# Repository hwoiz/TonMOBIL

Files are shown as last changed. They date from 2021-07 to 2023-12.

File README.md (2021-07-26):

# TonMOBIL-Box
## Meine Box
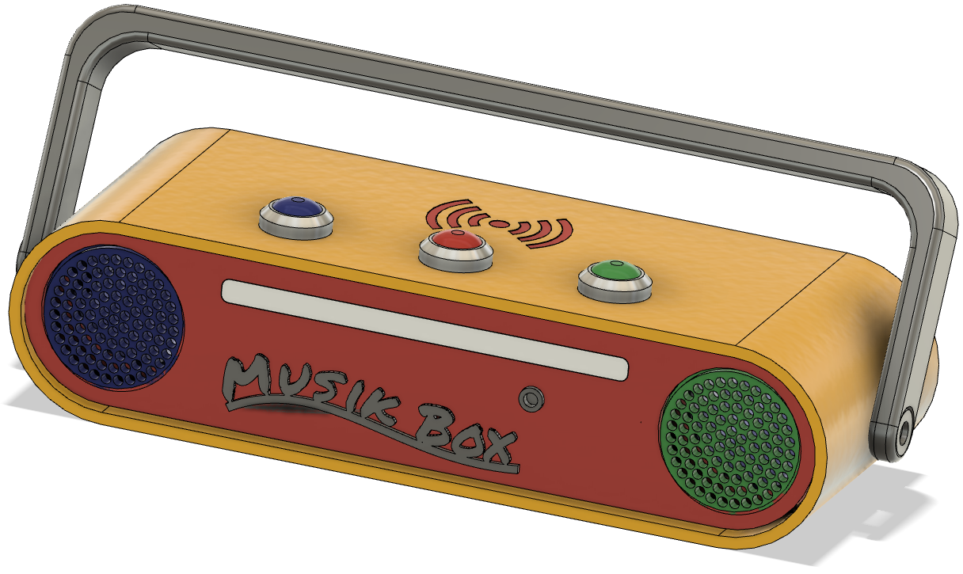
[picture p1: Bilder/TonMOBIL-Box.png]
TonMOBIL-Box

## Danksagung
Als Vorlage für mein Projekt diente das Projekt TonUINO von Thorsten Voß.
[https://www.voss.earth/tonuino](https://www.voss.earth/tonuino)

Viele Forenbeiträge aus [https://discourse.voss.earth](https://discourse.voss.earth/) haben mich animiert eine eigene Variante zu erstellen.
## Einleitung
Die Zeiten von Kasseten und CD sind inzwischen vorbei. Heute sind MP3-Dateien das Medium der Wahl.
Die TonMOBIL-Box basiert auf dem OpenSource Projekt TonUNIO. Es ermöglicht auch Kleinkindern selbstständig ihre Lieblings-MP3 abzuspielen. Sie verbinden eine Figur oder einen Button mit der Musik oder einem Hörspiel.
## Eigenschaften
- Die Eltern füllen die SD-Karte der Box mit der Lieblingsmusik, oder den Lieblingshörspielen und ordnen diese einem NFC-Tags zu. Diese Tags können in der Fußplatte von Figuren, Motivkarten oder Buttons eingebaut sein.
- Zur Nutzung der Box muss das Kind nur die mittlere Taste einmal kurz drücken, nach wenigen Sekunden beginnt die Box eine MP3-Datei aus dem Album Nummer 1 abzuspielen.
- Durch aufsetzen einer Figur, Karte oder Button auf die Oberseite der Box können nun auch andere Alben ausgewählt werden. Die Box unterbricht nach Abnehmen der Figur / Button die Wiedergabe nicht. Ein widerholtes Aufsetzen spielt das nächste Lied / Hörspiel. 
- Die Wiedergabe kann durch kurzen Druck pausiert werden. Ein erneuter Kurzer Druck setzt die Wiedergabe fort. Verbleibt die Box 5 Minuten im Pausenmodus, wird die Box ausgeschaltet.
- Im Pausenmodus können durch langen Druck (>2 Sek.) vordefinierte Alben abgespielt werden.
- Im Playmodus knn über die beiden äuseren Tasten mit kurzen Tastendruck die Lautstärke verändert werden. Mit einem langen Tastendruck (>2 Sek.) Kann durch die Titel des aktuellen Albums geblättert werden.
- Wird wird auf der Vorderseite ein Kopfhörer angeschlossen, werden die Lautsprecher abgeschaltet.
## 3D-Druck
Das Gehäuse wurde komplett mit einem 3D-Drucker erstellt. Das Gehäuse besteht aus den Elementen Vorderteil, Rückseite, Hülle, Bügel und einige Zusatzteile. Die beiden Schrauben am Bügel halten die Box kindersicher zusammen.

Für die 3mm-Schrauben wurden 3mm Messing-Einpress-Muttern in die gedruckten Teile eingeschmolzen.

Die für den Druck der Einzelteile sind die STL-Dateien im Verzeichnis [STL-Dateien](STL-Dateien) verfügbar. 

Die STL-Dateien wurden mit Fusion360 erstellt. Zur Modifikation der STL-Daten steht eine Exportdatei vom Fusion360-Projekt im Verzeichnis [Fusion360](Fusion360) zu Verfügung. Sie enthält neben den Gehäuseteilen auch alle Elektronikkomponemten als Modell.
## Hardware
Soweit es möglich war, wurden fertige Module benutzt. Dies vereinfacht den Aufbau der Schaltung. 

Die Schaltung des TonUINO wurde um folgende Elemente ergänzt:
- Kopfhörerbuchse mit Abschaltung der Lautsprecher.
- Einschalten der Box über die Play/Pause-Taste mit einem Pololu-Switch.
- Stromversorgung aus Akku, Lade-/Entladeschaltung und StepUp-Regler.
- Statusanzeige der Betriebszustände mit einem RGB LED-Streifen WS2812B mit 15 LED.
- Einen mit einer aufgebogenen Büroklammer nutzbaren Reset-Taster. (Er trennt den Akku von der Schaltung)

Für die Schaltung wurde eine Platine mit KICAD entwicket. Die für die Fertigung erforderliche Gerber-Datei ist im Ordner [KICAD](KICAD) verfügbar.

Der Schaltplan und die Verkabelung der Module können dem Handbuch [Technische Dokumentation (PDF)](Dokumente/TechnischeDokumentation.pdf) entnommen werden.
## Software
Die angepasste [Firmware](Firmware/TonMOBIL) für den Arduino basiert auf der Lösung von Thorten Voß. [github.com/xfjx/TonUINO](https://github.com/xfjx/TonUINO)
Sie wurde um folgende Eigenschaften ergänzt:
- Um das im Forumsbeitrag [mp3.getFolderTrackCount liefert falschen Wert](https://discourse.voss.earth/t/mp3-getfoldertrackcount-liefert-falschen-wert/3406) besprochene Fehlverhalten einiger MP3-Module zu umgehen, wurde in jeden Ordner eine Datei 000_Album-Nummer-xx.mp3 eingefügt. Sie enthält der Text Album Nummer ## und wird vor dem Aufruf von mp3.getFolderTrackCount abgespielt. Damit wird der Fehler in der Firmware von einigen MP3-Modulen umgangen.
- Statusanzeige in Form einer LED-Lichtleiste nach dem Vorschlag aus folgendem Forumsbeitrag: [https://discourse.voss.earth/t/integration-led-strip-und-ring-mit-neopixel/2760/8](https://discourse.voss.earth/t/integration-led-strip-und-ring-mit-neopixel/2760/8)
## Handbücher
Eine vollständige Beschreibung aller Funktionen findet sich im [Benutzerhandbuch (PDF)](Dokumente/Benutzerhandbuch.pdf).

Die technischen Details und die benötigten Bauteile können dem Handbuch [Technische Dokumentation (PDF)](Dokumente/TechnischeDokumentation.pdf) entnommen werden.

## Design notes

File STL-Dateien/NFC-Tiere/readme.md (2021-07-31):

## NFC-Tiere
Druckvorlagen für Tierfiguren. Die Figuren sind ca 7 cm hoch.

In die Bodenplatte kann ein NFC-Aufkleber von 25 mm Durchmesser eingefügt werden. Die Bodenplatte wird mit Sekundenkleber mit der Figur dauerhaft verklebt.

Die Figuren können mit Acrylfarben aus dem Modellbau nach eigener Vorstellung bemalt werden.

Die Maus
Frosch
Hund
Bär
Katze
Hase
Eichörnchen
Elefant

Die Vorlagen der Tierfiguren stammen aus öffentlich verfügbaren Internetquellen und wurden von mir in der Größe verändert und mit einer Bodenplatte für einen NFC-Aufkleber (25mm Durchmesser) versehen.

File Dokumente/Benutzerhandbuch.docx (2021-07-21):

# TonMOBIL

Benutzerhandbuch

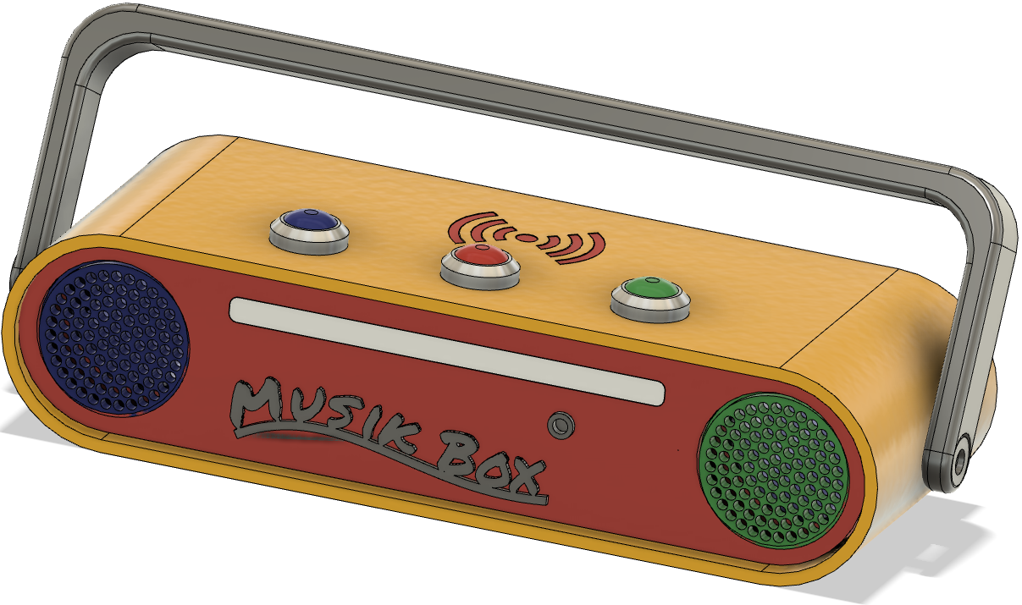
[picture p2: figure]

Version 2.1

# Vorwort

Die Zeiten von Kasseten und CD sind inzwischen vorbei. Heute sind MP3-Dateien das Medium der Wahl.

Die TonMOBIL-Box basiert auf dem OpenSource Projekt TonUNIO. Es ermöglicht auch Kleinkindern selbstständig ihre Lieblings-MP3 abzuspielen. Sie verbinden eine Figur oder einen Button mit der Musik oder einem Hörspiel.

Die Eltern füllen hierzu die SD-Karte der Box mit der Lieblingsmusik, oder den Lieblingshörspielen und ordnen die Titel einem NFC-Tags zu. Diese Tags sind in der Fußplatte der Figuren oder den Button eingebaut.

Zur Nutzung der Box muss das Kind die mittlere Tastenur nur kurz drücken, nach wenigen Sekunden beginnt die Box eine zufällige MP3-Datei aus dem Album Nummer 1 abzuspielen.

Durch aufsetzen einer Figur / Button auf die Oberseite der Box können nun auch andere Alben ausgewählt werden. Die Box unterbricht nach Abnehmen der Figur / Button die Wiedergabe nicht.

Um die Wiedergabe zu beenden, muss die mittlere Taste einmal kurz gedrückt werden, die Wiedergabe pausiert nun. Nach 5 Minuten ohne Wiedergabe schaltet die Box automatisch ab.

Auf der Vorderseite befindet sich ein Anschluss für einen 3,5 mm Kopfhörer. Wird dieser gesteckt, werden die Lautsprecher abgeschaltet.

Ich wünsche nun viel Freude beim Erkunden von über 1000 MP3-Dateien.

Harald Woizischke

©2021

NFC-Leser

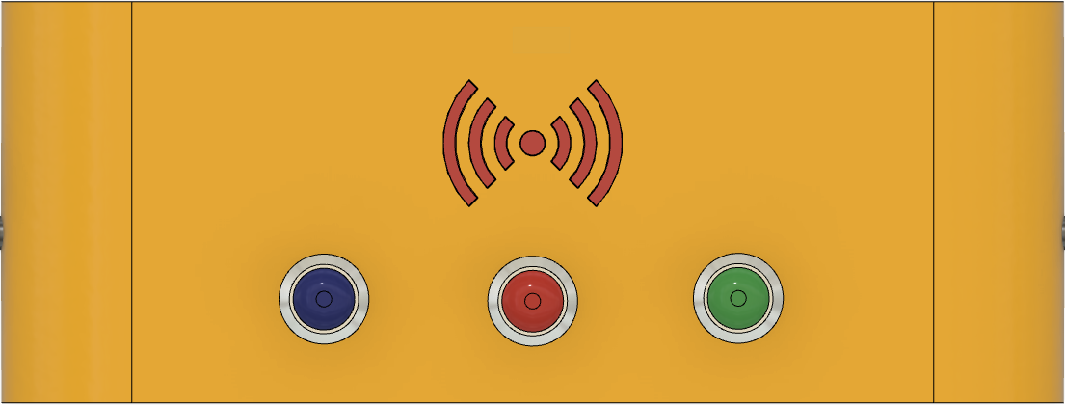
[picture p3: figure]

Leiser Play Lauter
Zurück Pause Vorwärts

Lautsprecher LED-Statusleiste Kopfhörer 3,5mm Lautsprecher

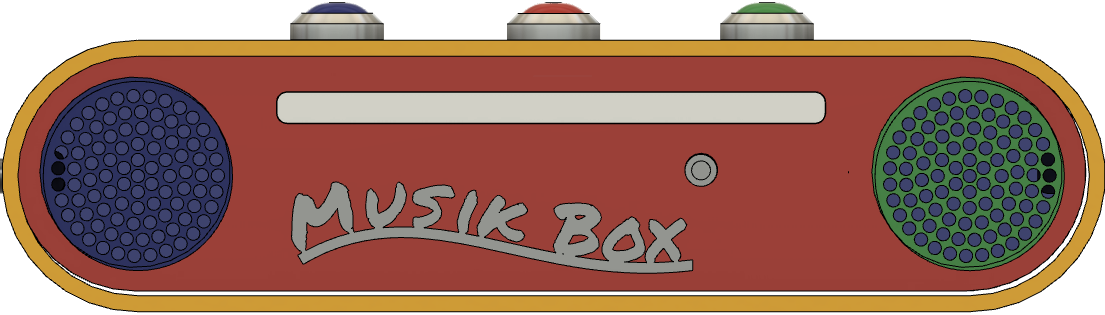
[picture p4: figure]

Resetöffnung SD-Karte Firmware Ladebuchse Ladekontrolleuchte
Update

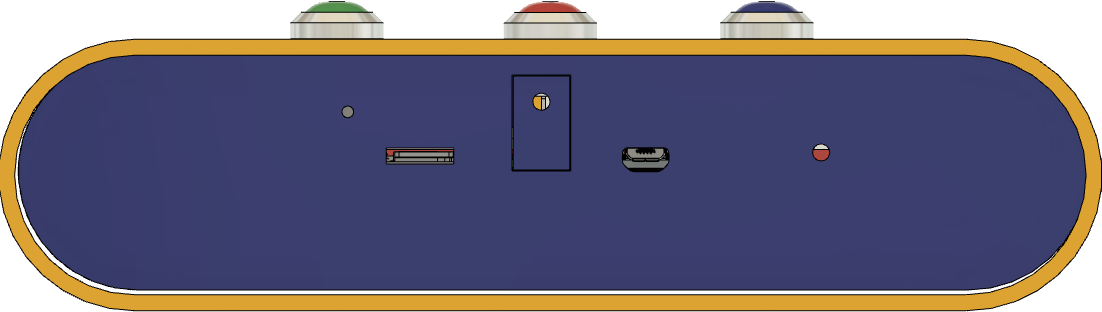
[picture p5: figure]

# Funktion der Tasten

Die Funktion der Tasten wechselt je nach aktuellen Betriebszustand.

## Einschalten

Die mittlere Taste kurz drücken und warten bis die Musik beginnt und die Statusanzeige leuchtet in Regenbogenfarben. Das bein Start abgepielte Album kann im Adminmenü verändert werden. Voreingestellt ist das Album Nummer 1.

## Ausschalten

Es gibt an der Box keinen Ausschalter. Sobald die Box im Pausenmodus ist, schaltet die Box nach 5 Minuten automatisch aus.

## Reset

Im Fehlerfall kann die Box kurzzeitig von der Stromversorgung getrennt werden. Auf der Rückseite gibt es oben links ein kleines Loch. Hier eine Nadel oder eine aufgebogene Büroklammer einstecken bis ein Klickgeräusch zu hören ist. Nun kann die Box über die mittlere Taste neu gestartet werden.

## Abspielen

Auswahl des Musik-/Hörspiel-Ordners erfolgt durch auflegen eines NFC-Tag (Figur oder Chip)

Mittlere Taste <2Sec: Play/Pause
Play = Statusanzeige leuchtet komplett in Regenbogenfarben
Pause = Statusanzeige zeigt einen durchlaufenden Punkt

Linke Taste <2Sec : Lautstärke verringern
Statusanzeige zeigt den Lautstärkepegel

Rechte Taste <2Sec: Lautstärke erhöhen
Statusanzeige zeigt den Lautstärkepegel

## Sonderfunktionen im Play-Modus

Mittlere Taste >5sec: Im Hörspiel-Modus Rücksprung auf 1. Titel.
In allen anderen Modi wird der aktuelle Titel unendlich wiederholt.

Linke Taste >5Sec: Vorherigen Titel im Ordner abspielen.

Rechte Taste >5Sec: Nächsten Titel im Ordner abspielen.

## Sonderfunktion im Pause-Modus

Linke Taste >2 sec: Album Nummer 2 wird abgespielt. Kann über das Adminmenü angepasst werden.

Mittlere Taste >2 sec: Album Nummer 3 wird abgespielt. Kann über das Adminmenü angepasst werden.

Rechte Taste >2 sec: Album Nummer 4 wird abgespielt. Kann über das Adminmenü angepasst werden.

Alle 3 Tasten gleizeitig: Adminmenü. Die möglichen Einstellungen werden angesagt.

## Tastenbelegung im Adminmenü

Mittlere Taste <2Sec: Auswahl bestätigen.

Linke Taste <2Sec : Voherige Option

Rechte Taste <2Sec: Nächste Option

Linke Taste >5Sec: 10 Optionen zurück

Linke Taste >5Sec: 10 Optionen vorwärts

Mittlere Taste DoppelClick: Ansage der aktuellen Option

Mittlere Taste >2Sec: Abruch Untermenü oder Elternmenü

## Tastenbelegung während der Programmierung eines NFC-Tags

Mittlere Taste <2Sec: Auswahl bestätigen.

Linke Taste <2Sec : Voheriger Ordner, Titel oder Modus

Rechte Taste <2Sec: Nächste Ordner, Titel oder Modus

Linke Taste >2Sec: 10 Ordner, Titel zurück

Linke Taste >2Sec: 10 Ordner, Titel vorwärts

Mittlere Taste DoppelClick: Ansage des aktuellen Ordners, Titel oder Modus

Mittlere Taste >2Sec: Abruch NFC Programmierung

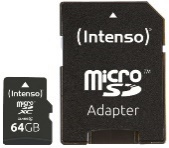
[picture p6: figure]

# SD-Karte befüllen

Die Ansagen und die Musik/Hörspiele sind auf einer SD-Karte gespeichert. Zum Ändern und Ergänzen des Inhalts kann die SD-Karte auf der Rückseite der Box durch Eindrücken und Herausziehen entnommen werden.

Zum Befüllen der SD-Karte am PC wird ein Adapter oder ein USB SD-Card Reder benötigt.

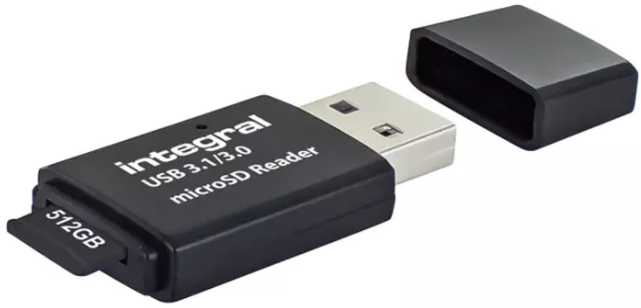
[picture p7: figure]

## Verzeichnisstruktur

Die Ordner „advert“ und „mp3“ enthalten die Ansagen der Box und sollten weder verändert, noch gelöscht werden.

Zur Speicherung von Musik und Hörspielen können bis zu 99 Ordner angelegt werden. Die Ordner erhalten die Namen 01 bis 99 und müssen fortlaufend nummeriert sein. In jedem Ordnern können nun bis zu 255 Musik/Hörspiele als mp3-Datei abgespeichrt werden.

## Windows-Programm

Die Dateien müssen mit mit einer dreistelligen Zahl beginnen und können optional mit Text ergänzt werden.

Am besten man nimmt zum Kopieren der MP3-Dateien das Programm „TinoTool“.

Eine Beschreibung und den Link zum Download gibt es hier: https://discourse.voss.earth/t/tinotool-windows-gui-zum-sd-karte-befuellen/2400

Beispiel:

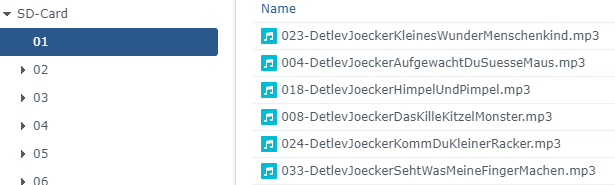
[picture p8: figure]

Damit für die zufällige Wiedergabe die richtige Anzahl der in einem Ordner vorhandenen Dateien ermittelt werden kann, muss in jedem Ordner eine Datei mit dem Namen 000_Album-Nummer-##.mp3 existieren. Die Datei enthält den Text „Album Nummer 1 …“. Diese Dateien können im Internet unter https://ttsmp3.com/text-to-speech/German/ erstellt werden. Als Stimme wurde German/Viki gewählt.

# NFC-Tag (Figuren / Button) zuordnen

Die Auswahl der anzuspielenden Mp3-Dateien erfolgt durch auflegen eines NFC-Tag. Diese sind im Boden der Figuren integriert.

Die Box benötigt NFC-Tags mit 13,56 MHZ. Es gibt baugleiche Tags mit 125kHz, diese fuktionieren aber nicht.

Diese Tags gibt es in unterschiedlichen Bauformen. Für Figuren eignen sich besonders NFC-Chips oder NFC-Aufleber mit 25mm Drchmesser. Alternativ können auch NFC-Karten eingesetzt werden. Diese können sehr gut mit Aufklebern beidseitig beschriftet werden.

## Programmieren mit der Box

Im Adminmenü können die NFC-Tags mit einem Order oder Titel verknüpft werden. Hierzu den NFC-Tag auf die Box auflegen und den Sprachanweisungen folgen. Der Tag darf erst wieder vom Gerät genommen werden, wenn die Programmierung vollständig abgeschlossen wurde.

## Adminmenü

Die möglichen Programmierschritte werden von der Box angesagt. Das Adminmenü kann druch einen langen Druck auf die mittlere Taste abgebrochen werden.

### Eine Karte neu konfigurieren

Einen NFC-Tag auflegen und diesen bis zum Abschluss der Programmierung auf der Box belassen. Die einzelnen programmierschritte werden angesagt. (siehe Verfügbare Abspielmodi)

### Maximallautstärke festlegen

Hier kann die maximal mögliche Lautstärke der Box beschränken.

### Minimallautstärke festlegen

Hier kann die minimal mögliche Lautstärke eingestellt werden.

### Lautstärke beim Start festlegen

Nach dem Einschalten beginnt die Box mit dieser Lautstärke die Wiedergabe.

### EQ konfigurieren

Die Klangfarbe der Wiedergabe kann an persönliche Vorlieben angepasst werden.

### Modifikationskarte festlegen

Mit diesen Karten kann das Verhalten der Box beeinflusst werden.
Folgende Modifikationskarten werden unterstützt:

- Schlummermodus. Nach einer festgelegten Zeit wird die Wiedergabe angehalten und die Box wechselt in den Pausenmodus
- Stopptanz. Die Wiedergabe wird nach einem Zufallsmodus für wenige Sekunden unterbrochen und dann wieder fortgesetzt.
- TonUINO sperren. Der Zugang zum Adminmenü wird gesperrt. Es wird nun eine Adminkarte erstellt mit der man zukünftig ins Adminmenü kommt. Der Zugang über das gleichzeitige Drücken der 3 Tasten ist nicht mehr möglich.
- Krabblermodus. Die Bedienung über die Tasten wird verhindert. Eine Wiedergabe ist nur über eine Figur / Button möglich.
- Kitamodus. Die aktuell abgespielte MP3-Datei wir nicht durch erleutes Auflegen einer Figur / Buttons unterbrochen. Erst nach Ende der Datei wird der neue Titel wiedergegeben.
- Titel wiederholen. Den aktuell abgespielten Titel endlos wiederholen.

### Tasten mit einem Shortcut konfigurieren

Die 3 Tasten können mit einem Album verknüpft werden. Im Pause-Modus kann durch langes drücken einer Taste die Wiedergabe gestartet werden

### Den Timer konfigurieren

Falls die Box keine Musik spielt, wird nach der hier festgelegten Zeit die Box abgeschaltet.

### Einzelkarten für einen Ordner erstellen

Will man mit einer Figur / Button nur eine einelne Datei eines Ordner abpielen, kann hier eine entsprechende Figur /Button definiert werden.

### Funktion der Lautstärketasten umdrehen.

Hier kann die Funktion der linken und rechten Taste so geändert werden, das der Liedwechsel bei kurzem Tastendruck, und die Lautstärkeänderung bei langem Tastendruck erfolgt.

### Alle Einstellungen löschen

Alle im Adminmenü vorgenommenen Einstellungen werden auf Standardwerte zurückgesetzt.

### Das Adminmenü absichern

Der Zugang zum Adminmenü kann über eine zusätzliche Tastenkombination abgesichert werden.

## Programmierung mit NFC-fähigem Android-Handy

Alternativ kann die Programmierung der Figuren /Button auch mit einem Android-Handy mit NFC-Funktionalität erfolgen.
Hierzu aus dem Playstore die App TonUINO NFC Tools installieren.
Um die volle Funktionalität zu erhalten ist in der App die Version Tonuino 2.1.x auszuwählen.
Auch hier darf das Tag erst nach vollständiger Programmierung vom Handy entfernt werden.

Für iOS gibt es derzeit noch keine entsprechende App.

## Verfügbare Abspielmodi

Für die mit NFC-Tagverknüpften Dateien kann eine der folgenden Abspiel-Modi definiert werden:

#### Hörspiel

Ein zufälliger Titel aus dem gewählten Ordner wird abgespielt. Danach wird die Wiedergabe gestoppt.

#### Album

Spielt alle Titel des Ordners in nummerischer Reihenfolge.

#### Party

Spielt zufällige Titel des Ordners in Endlosschleife.

#### Einzelmodus

Wiedergabe einer einzelnen Datei

#### Hörbuch

Spielt alle Titel des Ordners in nummerischer Reihenfolge und speichert den Fortschritt, sodass beim nächsten Verwenden wieder beim aktuellen Titel begonnen wird.

#### Adminfunktionen

Mit dieser Figur / Button wird das Adminmenü gestartet.

#### Spezialmodus von-bis (Hörspiel)

Spielt einen zufälligen Titel aus dem ausgewählten Bereich eines Ordners.

#### Spezialmodus von-bis (Album)

Spielt alle Titel aus dem ausgewählten Bereich eines Ordners.

#### Spezialmodus von-bis (Party)

Spielt alle Titel aus dem ausgewählten Bereich eines Ordners in zufälliger Reihenfolge.

# Stromversorgung

Die Box wird von einem Akku mit Strom versorgt. Er kann mit einem USB-Ladegerät (Handy-Ladegerät) über die MicroUSB-Buchse auf der Rückseite der Box geladen werden.

Während des Ladevorgangs leuchtet die rote Ladeleuchte auf der Rückseite der Box. Diese erlischt sobald der Akku vollständig geladen ist. Eine Akkuladung reicht je nach Lautstärke, für 5 bis 10 Stunden Wiedergabe.

[Hier eingeben]

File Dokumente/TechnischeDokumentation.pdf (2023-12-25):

# TonMOBIL

## Technische Dokumentation

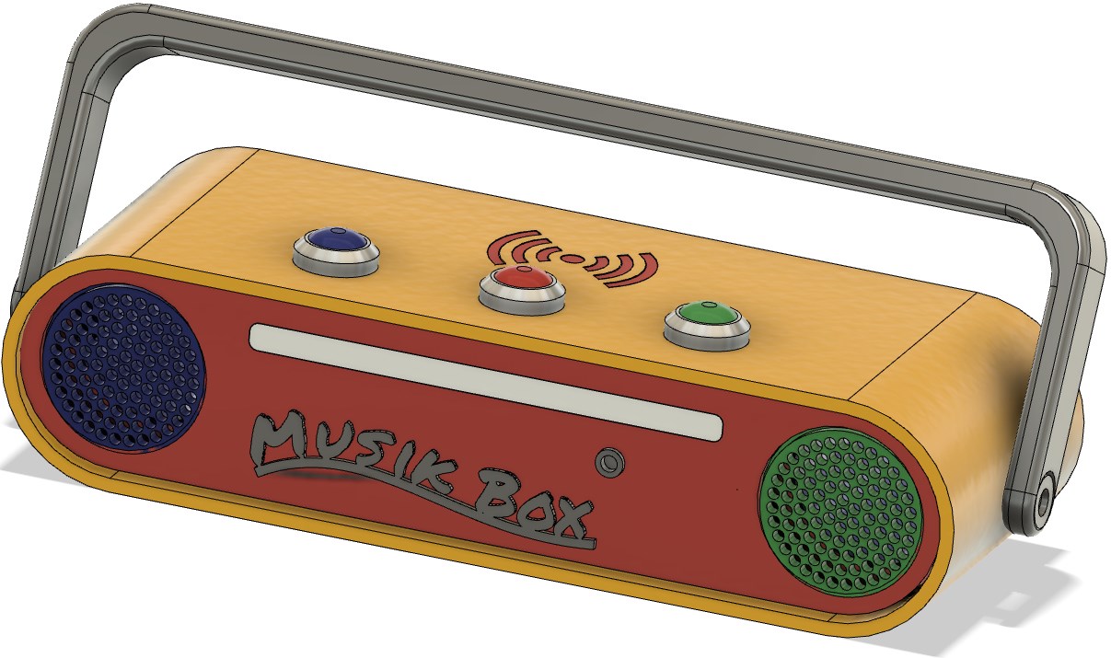
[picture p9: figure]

Version 1.0

## Inhalt

## Bedienelemente

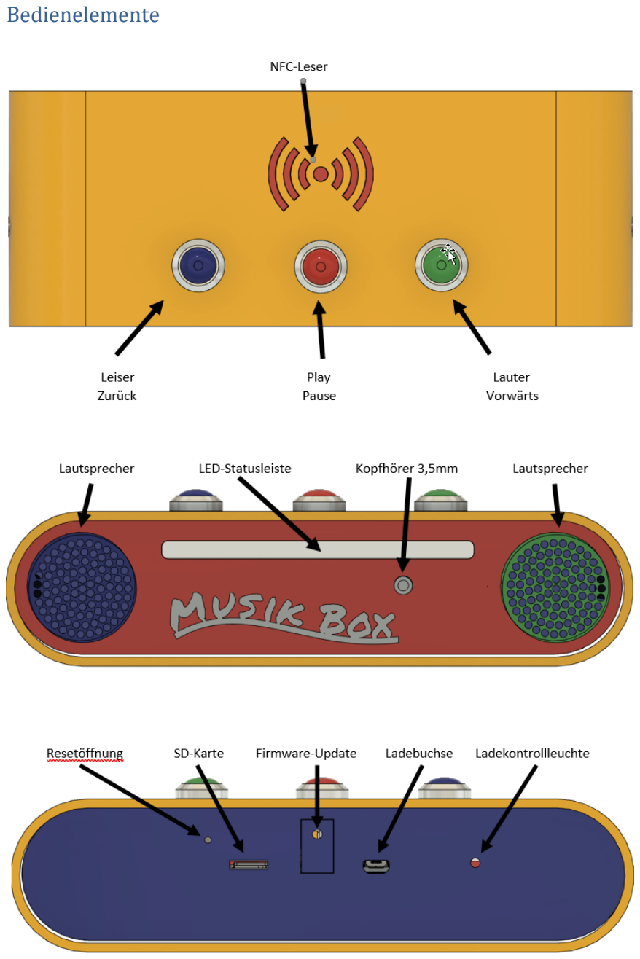
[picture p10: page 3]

## Einführung

Die Idee der Box entstammt dem OpenSource Projekt „TonUNIO“ von Thorsten Voß. http://tonuino.de/

Zu diesem Projekt gibt es eine Vielzahl von Abwandlungen der Schaltung und Software.

Die hier beschrieben Lösung wurde von Harald Woizischke entwickelt. (info@woizischke.de, 0160 6125 146). Als Basis wurde die Hard- und Software von Thorsten Voß genutzt.

Für die Statusanzeige in Form einer LED-Lichtleiste wurde die Firmware nach dem Vorschlag von tON aus folgendem Forumsbetrag ergänzt. https://discourse.voss.earth/t/integration-led-strip-und-ring-mit-neopixel/2760/8 (https://discourse.voss.earth/t/integration-led-strip-und-ring-mit-neopixel/2760/8)

Durch einen Fehler in der Firmware können einige DF-Player-Module die Anzahl der Dateien in einem Ordner nur dann ermitteln, wenn bereits eine Datei aus dem Ordner abgespielt wurde. Durch diesen Fehler versucht die Software auf Dateien zuzugreifen, die im Ordner nicht vorhanden sind, und stürzt dann ab. Um dieses zu umgehen wurde die Software, in Anlehnung an einen Änderungsvorschlag aus dem TonUINO-Forum, ergänzt. Jeder Ordner enthält nun zusätzlich eine Datei mit der Ordnungsnummer 000. Als Text enthält sie die Nummer des Albums. Diese Datei wird immer zuerst abgespielt und erst danach wird die Anzahl der Dateien ermittelt. So kann das Firmwareproblem des Moduls umgangen werden.

## Schaltplan

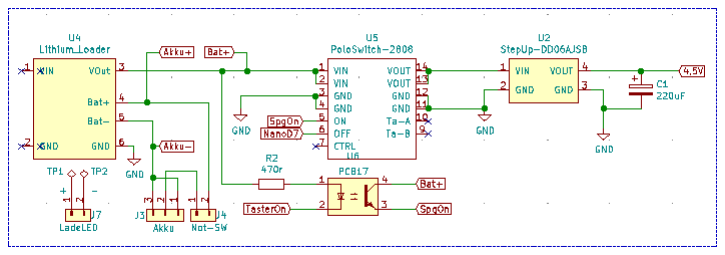
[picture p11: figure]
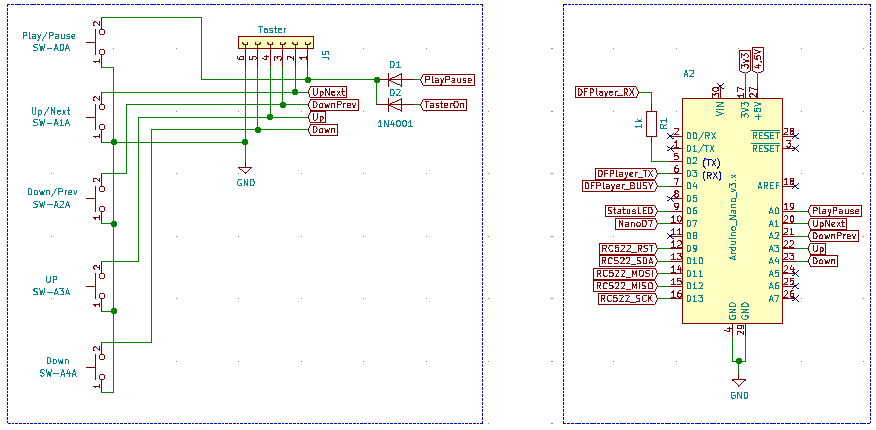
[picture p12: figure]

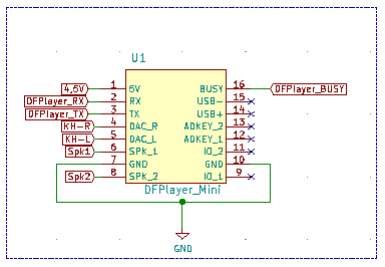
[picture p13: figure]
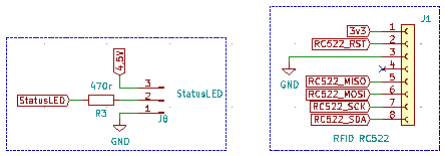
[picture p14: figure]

## Firmware

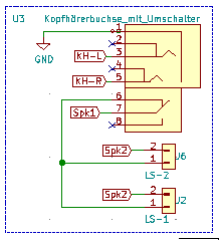
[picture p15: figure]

Die Software für den Prozessor auf dem Arduino Nano kann mit der Anwendung Arduino IDE (siehe arduino.cc) (https://www.arduino.cc/en/Main/Software) angepasst, compiliert und auf den Arduino Nano übertragen werden.

Die aktuelle Version der Firmware liegt in GitHub unter https://github.com/hwoiz/TonMOBIL/tree/main/Firmware

Die Version TonMobilLED (https://github.com/hwoiz/TonMOBIL/tree/main/Firmware/TonMobilLED) ist für die in diesem Handbuch beschriebene Box die richtige Version.

Die Version MiraHolzBox (https://github.com/hwoiz/TonMOBIL/tree/main/Firmware/MiraHolzBox) ist für eine hier nicht näher beschriebene Box ohne LED-Leiste.

Bevor die Firmware compiliert und auf den Arduino Nano übertragen werden kann, müssen in der Arduino-IDE folgende Einstellungen gemacht werden:

- Bibliotheken
- MFRC522
- DFPlayer Mini Mp3 by Makuna
- JC_Button
- Adafruit_NeoPixel (nur bei TonMobilLED)
- Tools -> Board : „Arduino Nano“
- Tools -> Prozessor : „ATmega328P (Old Bootloader)
- Tools -> Port : com4“ (Im Gerätemanager den richtigen Com-Port ermitteln)

Zuletzt drückt ihr den Hochladen-Button und die Firmware wird auf den Arduino.

## Platine

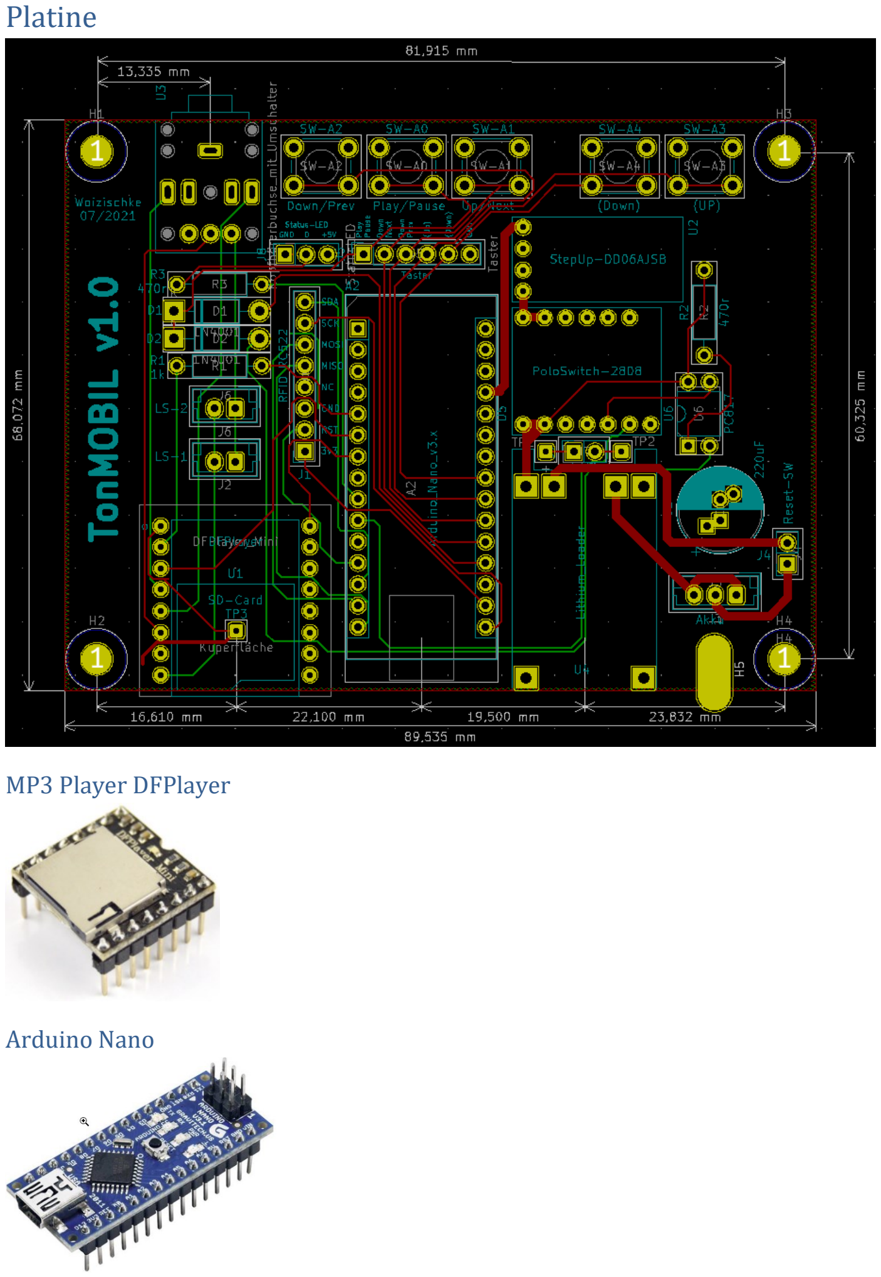
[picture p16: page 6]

### MP3 Player DFPlayer

### Arduino Nano

### RFID RC522 Modul

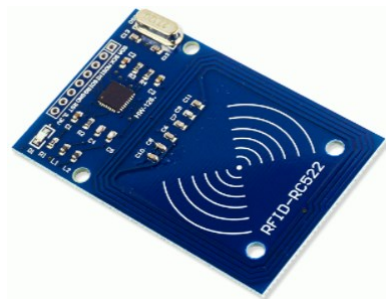
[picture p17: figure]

### Taster

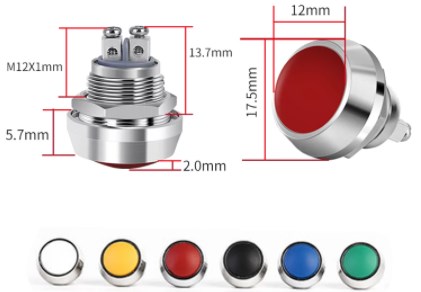
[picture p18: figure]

Es werden 3 Stück mit unterschiedlichen Farben benötigt.

### Lautsprecher

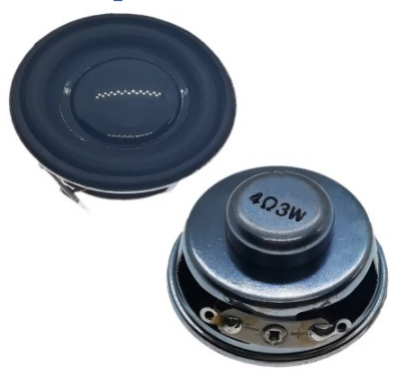
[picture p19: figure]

3W 4Ω

### Pololu-Switch

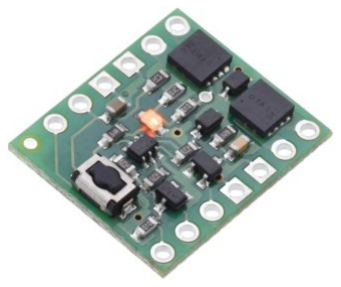
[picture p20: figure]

### TP4056 Lademodul

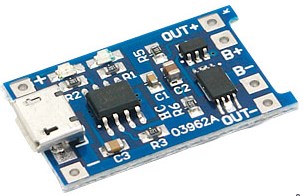
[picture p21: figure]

### StepUp-Wandler DD06AJSB

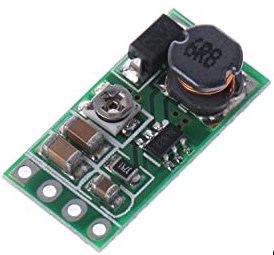
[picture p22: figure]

### LiPo Zelle

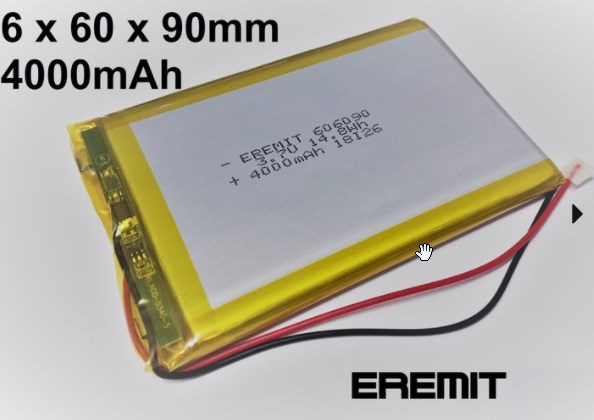
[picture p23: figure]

https://www.eremit.de/p/eremit-3-7v-4-000mah-high-cap

### RGB LED- Streifen WS2812B

Abschnitt von 15 LED aus Streifen mit 144 LED / m.

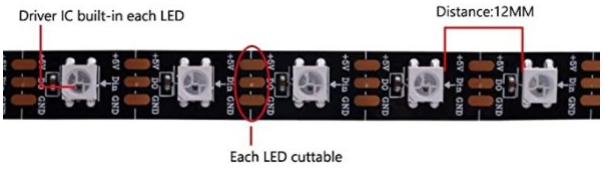
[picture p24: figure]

### MicroSwitch als Resettaster

### Optokoppler PC817

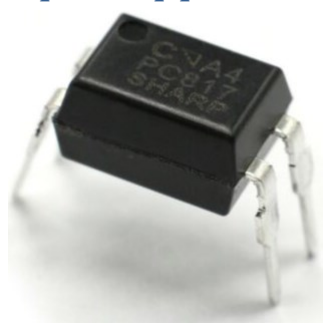
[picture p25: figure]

### Widerstände

2 Stück 470 Ω
1 Stück 1 kΩ

### Dioden

2 Stück N4001

### Steckverbinder

3 Stück XH2.54mm 2pol

1 Stück XH2.54mm 3pol

### Buchsenleiste

1 Stück 2pol gerade (Ladekontrollleuchte)

1 Stück 3pol gerade (LED-Statusleiste)

1 Stück 6pol gerade (Taster)

1 Stück 8pol gerade (NFC-Reader RC522)

### Stiftleisten

1 Stück 2pol abgewinkelt (Ladekontrollleuchte)


1 Stück 3pol abgewinkelt (LED-Statusleiste)

1 Stück 6pol abgewinkelt (Taster)


1 Stück 8pol abgewinkelt (NFC-Reader RC522)

## Gehäuseteile im 3D-Druck


Abbildung 1: Gesamtansicht

Abbildung 2: Vorderteil


Abbildung 3: Rückteil

Abbildung 4: Abdeckung LED-Leiste

Abbildung 5: Lautsprecher-Abdeckung (2x)


Abbildung 6: Träger für Platine

Abbildung 7: Abdeckung Firmwarebuchse

Abbildung 8: Aussenhülle


Abbildung 9: Halter NFC-Leser und Reset-Taster

Abbildung 10: NFC-Logo

Abbildung 11: Tragebügel

Abbildung 12: Befestigungsbuchse für Tragebügel (2x)

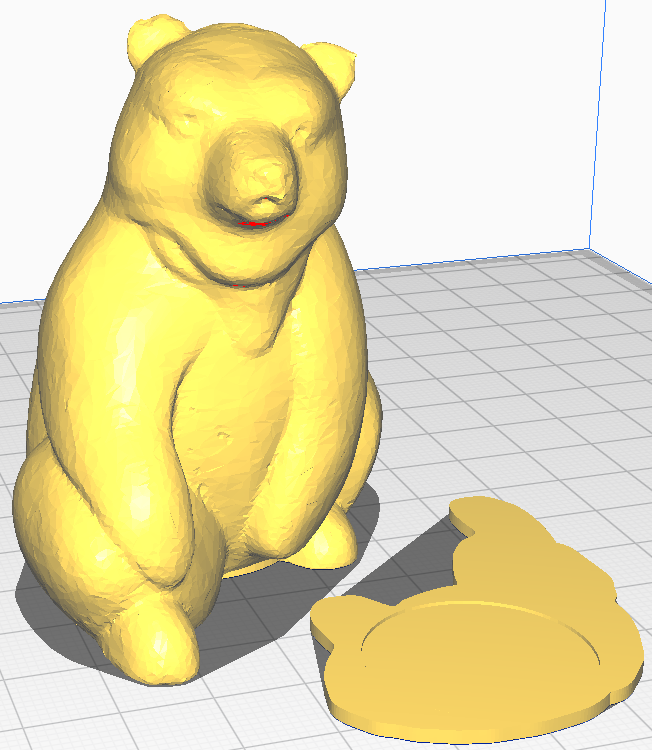
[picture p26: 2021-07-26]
STL-Dateien/NFC-Tiere/Bär.png

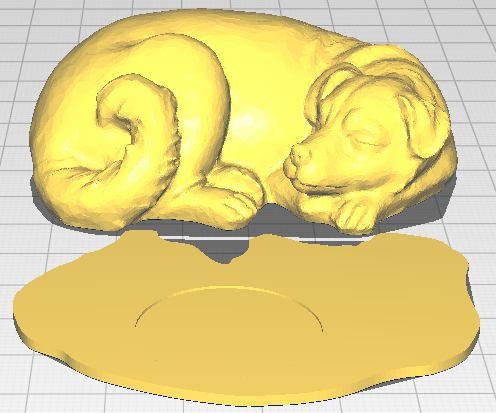
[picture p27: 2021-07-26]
STL-Dateien/NFC-Tiere/Hund.png

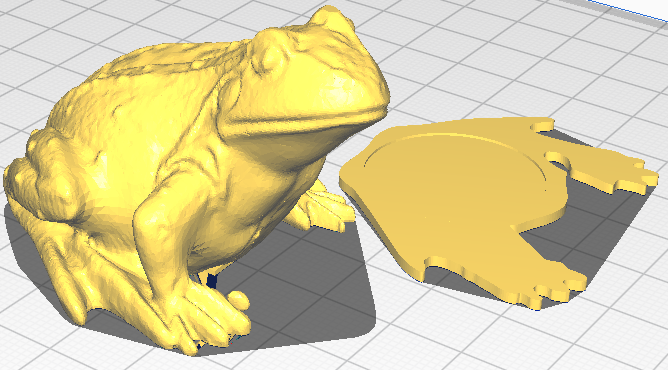
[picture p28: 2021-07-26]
STL-Dateien/NFC-Tiere/Frosch.png

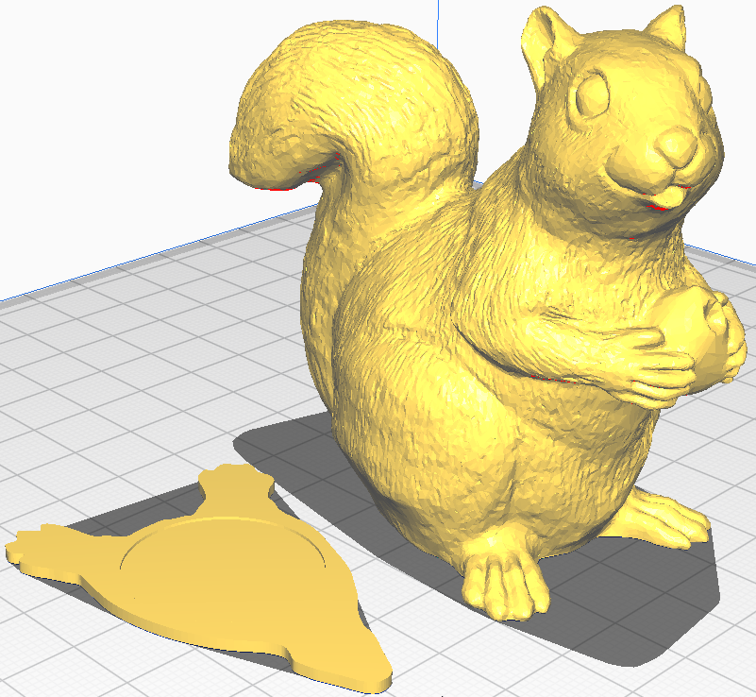
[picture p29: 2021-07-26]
STL-Dateien/NFC-Tiere/Eichörnchen.png

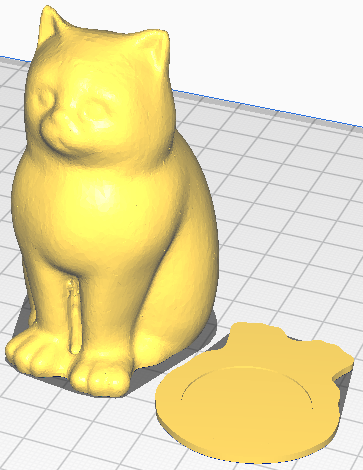
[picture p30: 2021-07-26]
STL-Dateien/NFC-Tiere/Katze.png

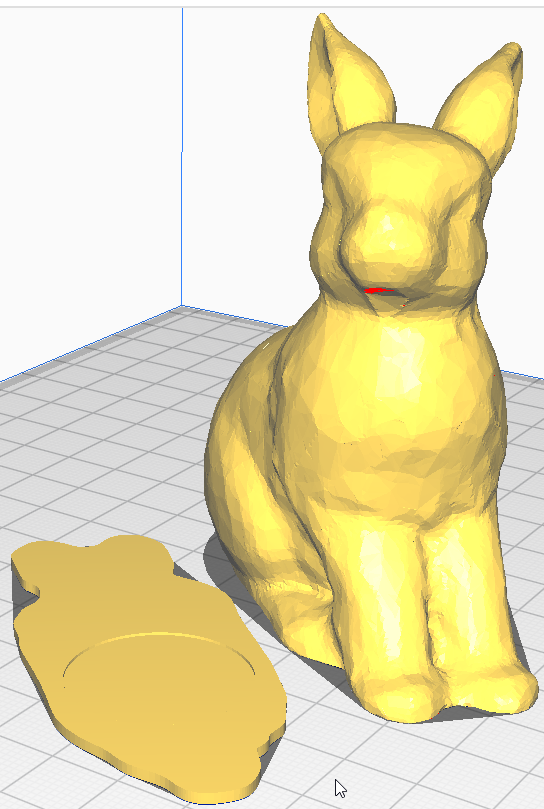
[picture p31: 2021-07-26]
STL-Dateien/NFC-Tiere/Hase.png

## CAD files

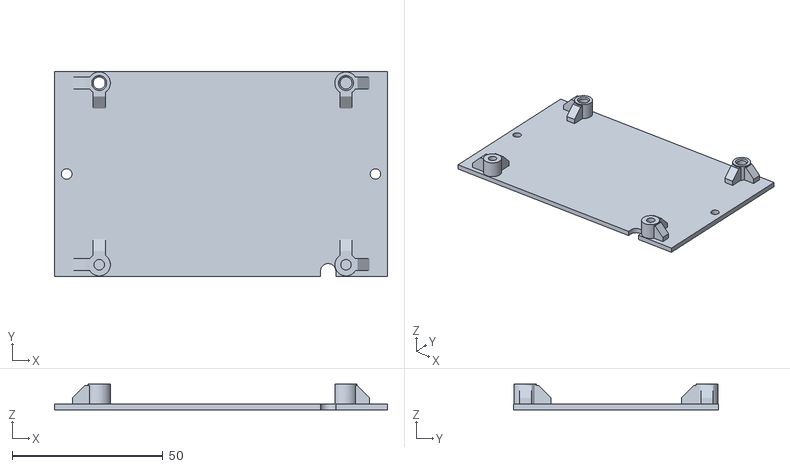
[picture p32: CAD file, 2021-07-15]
STL-Dateien/Gehäuse/Träger-Mainboard.stl
110.5 x 68.0 x 8.50

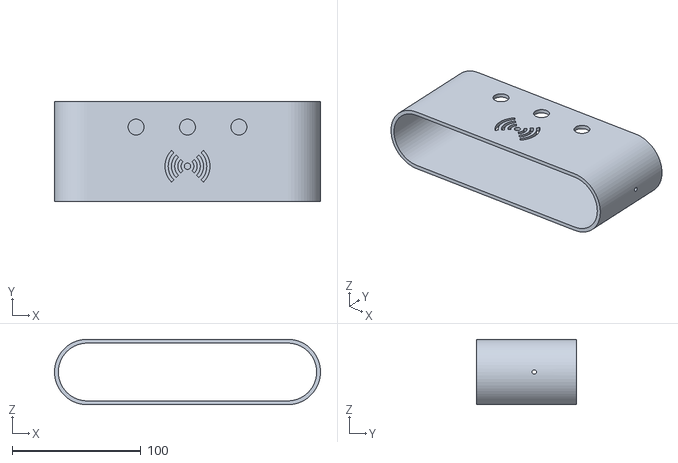
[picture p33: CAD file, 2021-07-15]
STL-Dateien/Gehäuse/Hülle.stl
206.9 x 78.0 x 50.9

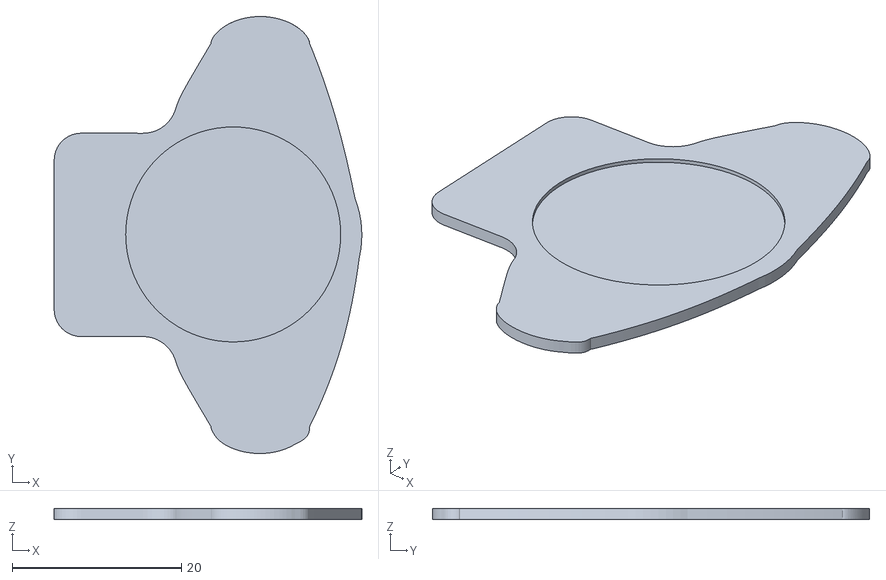
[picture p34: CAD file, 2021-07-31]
STL-Dateien/NFC-Tiere/Die Maus-Boden.stl
36.4 x 51.6 x 1.28

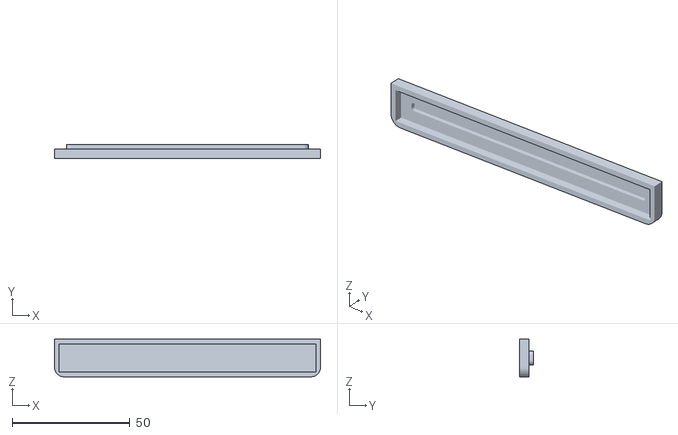
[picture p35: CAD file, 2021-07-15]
STL-Dateien/Gehäuse/Lichtleiste.stl
113.0 x 6.00 x 16.0

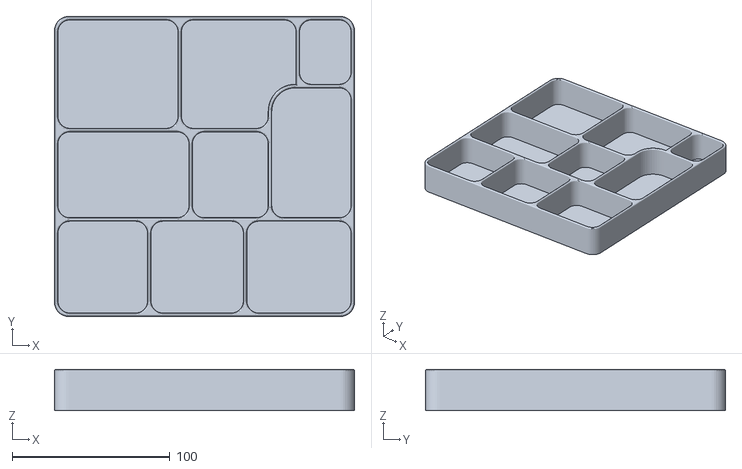
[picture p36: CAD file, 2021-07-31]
STL-Dateien/NFC-Tiere/Aufbewahrungskasten.stl
190.0 x 190.0 x 26.2

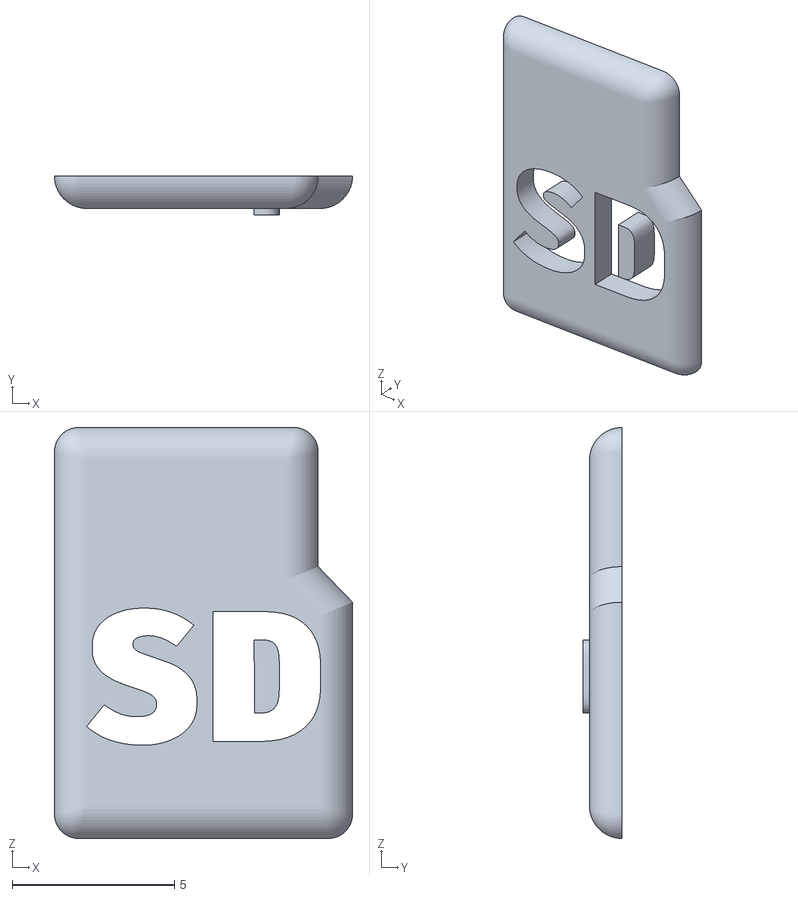
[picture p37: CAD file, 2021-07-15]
STL-Dateien/Gehäuse/SD-Card.stl
9.20 x 1.20 x 12.7

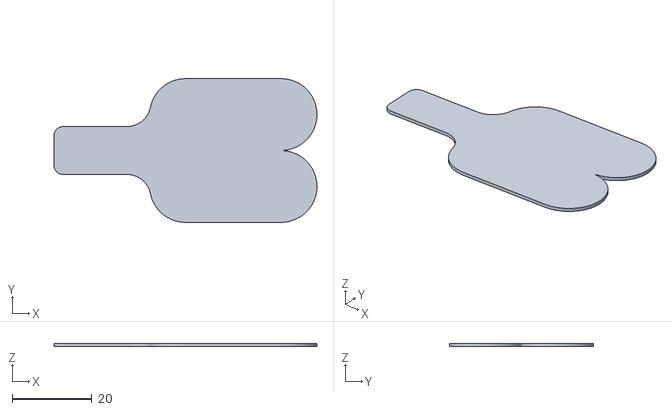
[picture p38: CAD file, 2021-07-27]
STL-Dateien/NFC-Tiere/Elefant-Bodendeckel.stl
66.0 x 36.1 x 0.8

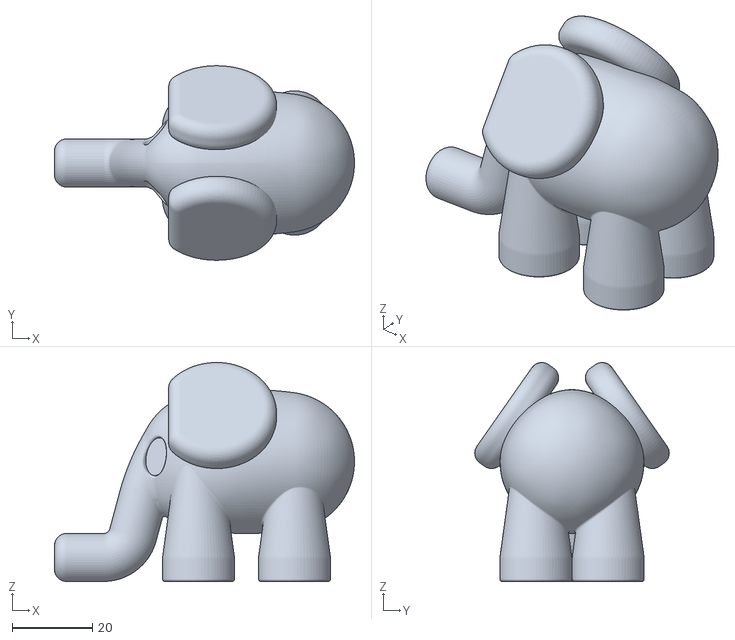
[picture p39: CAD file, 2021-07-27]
STL-Dateien/NFC-Tiere/Elefant.stl
75.0 x 48.6 x 54.8

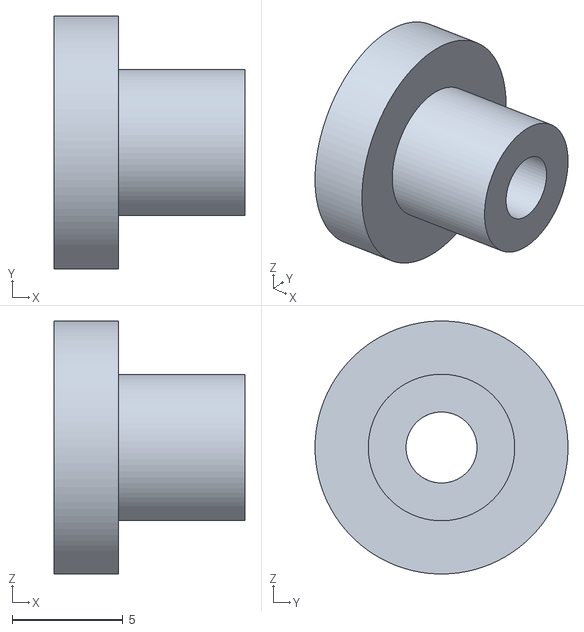
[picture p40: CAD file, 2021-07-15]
STL-Dateien/Gehäuse/Bügelbuchse.stl
8.60 x 11.4 x 11.4

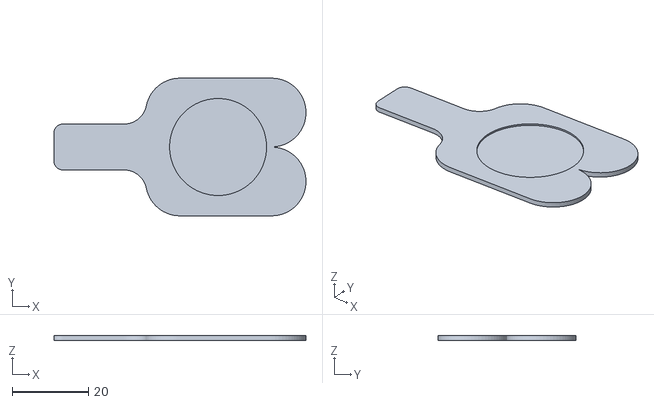
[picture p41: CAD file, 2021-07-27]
STL-Dateien/NFC-Tiere/Elefant-Boden.stl
66.0 x 36.1 x 1.20

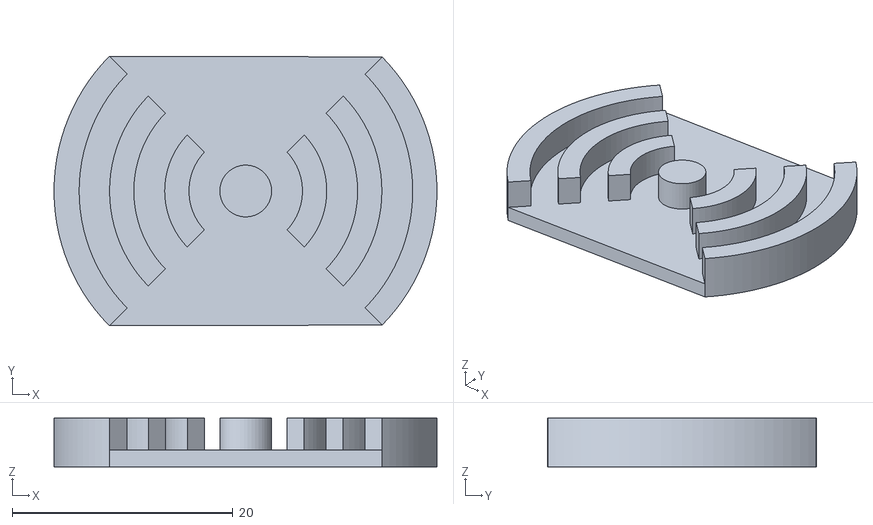
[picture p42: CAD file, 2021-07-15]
STL-Dateien/Gehäuse/NFC-Logo.stl
34.7 x 24.4 x 4.40

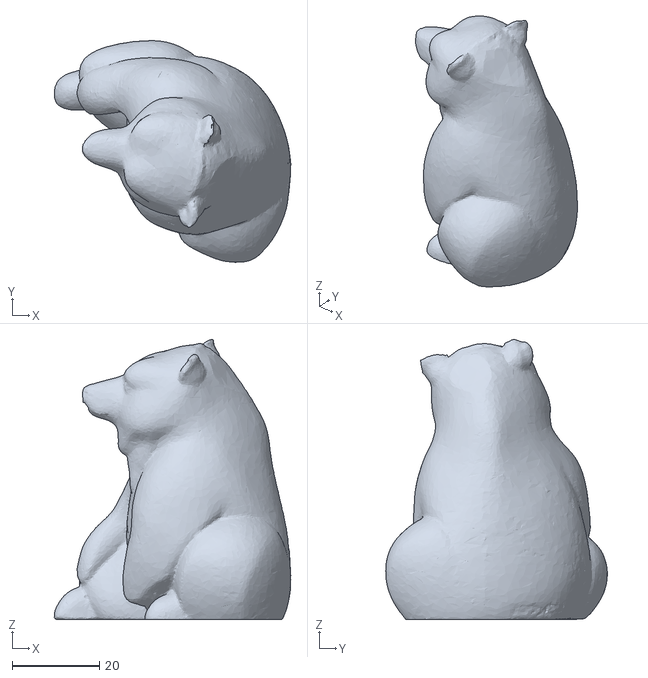
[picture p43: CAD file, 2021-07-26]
STL-Dateien/NFC-Tiere/Bär.stl
54.1 x 50.7 x 64.0

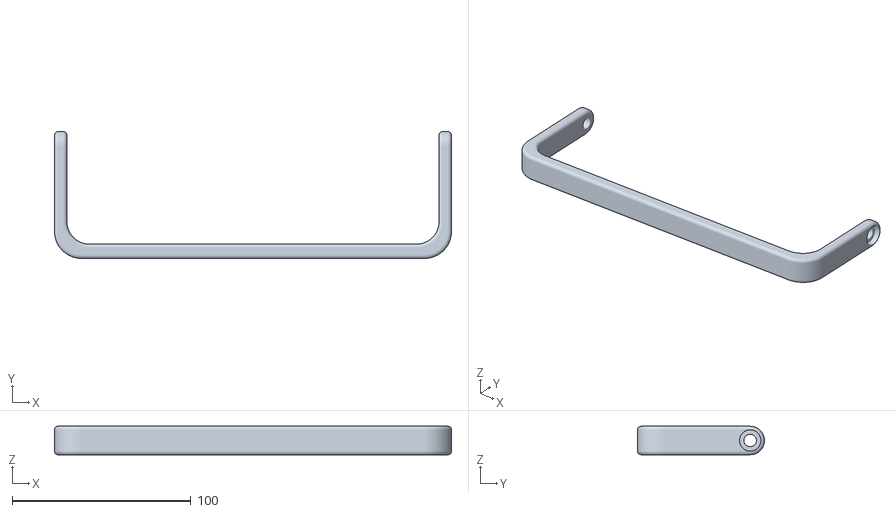
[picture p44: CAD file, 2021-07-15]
STL-Dateien/Gehäuse/Bügel.stl
222.1 x 71.0 x 16.0

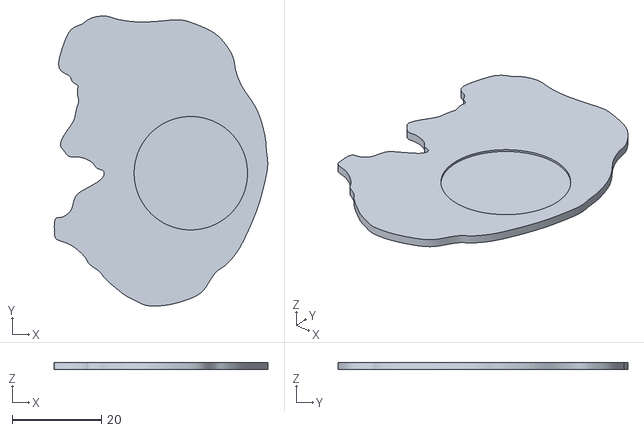
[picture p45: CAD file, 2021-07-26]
STL-Dateien/NFC-Tiere/Hund-Boden.stl
47.8 x 64.9 x 1.60

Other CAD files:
STL-Dateien/Gehäuse/5V.stl
STL-Dateien/NFC-Tiere/Eichhörnchen-Boden.stl
STL-Dateien/Gehäuse/Rückteil.stl
STL-Dateien/NFC-Tiere/Katze.stl
STL-Dateien/Gehäuse/Firmware-Deckel.stl
STL-Dateien/Gehäuse/Gitter.stl
STL-Dateien/Gehäuse/Logo.stl
STL-Dateien/Gehäuse/NFC_Switch-Halter.stl
STL-Dateien/Gehäuse/Vorderteil.stl
STL-Dateien/NFC-Tiere/Bär-Boden.stl
STL-Dateien/NFC-Tiere/Frosch-Boden.stl
STL-Dateien/NFC-Tiere/Hase-Boden.stl
STL-Dateien/NFC-Tiere/Hase.stl
STL-Dateien/NFC-Tiere/Hund.stl
STL-Dateien/NFC-Tiere/Katze-Boden.stl

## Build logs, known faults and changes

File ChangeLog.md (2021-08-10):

# Change Log
## 1.5
Die Shortcut-Tasten werden nach einem Reset vorbelegt.
- Ordner 1 wird im Party-Modus beim Start abgespielt.
- Ordner 2 wird im Party-Modus bei langem Druck auf die linke Taste abgespielt.
- Ordner 3 wird im Party-Modus bei langem Druck auf die mittlere Taste abgespielt.
- Ordner 4 wird im Party-Modus bei langem Druck auf die rechte Taste abgespielt.
Die Shortcut-Zuordnungen können wie bisher über das Admin-Menü verändert werden.

Die Aufteilung in mehrer Einzeldateien hat sich nicht bewährt und wurde zurückgenommen.

Unnötige Befehle zum Deep-Sleep aus der Funktion checkStandbyAtMillis() entfernt.
## 1.4
LED-Animation während der Startphase. Von Rot über Gelb bis Grün.
## 1.3
Zur besseren Wartbarkeit wurde die ino-Datei in mehrere Einzeldateien aufgeteilt.
## 1,2
Der LED-Strip wird nun direkt beim Start eingeschaltet
## 1.1
Erstversion

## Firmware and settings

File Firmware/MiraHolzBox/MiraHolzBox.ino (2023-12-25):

/*
  _______          __  __ _           _    _       _     
 |__   __|        |  \/  (_)         | |  | |     | |    
    | | ___  _ __ | \  / |_ _ __ __ _| |__| | ___ | |____
    | |/ _ \| '_ \| |\/| | | '__/ _` |  __  |/ _ \| |_  /
    | | (_) | | | | |  | | | | | (_| | |  | | (_) | |/ / 
    |_|\___/|_| |_|_|  |_|_|_|  \__,_|_|  |_|\___/|_/___|
                                                         
                                                         
    TonUINO Version 2.1 - TonUINO für Miras Holz-Box

    created by Thorsten Voß and licensed under GNU/GPL.
    Information and contribution at https://tonuino.de.
    
    Advance by Harald Woizischke 
*/

char version[] = "1.5";

#include <DFMiniMp3.h>
#include <EEPROM.h>
#include <JC_Button.h>
#include <MFRC522.h>
#include <SPI.h>
#include <SoftwareSerial.h>
#include <avr/sleep.h>


// uncomment the below line to enable five button support
//#define FIVEBUTTONS

// uncomment the below line to flip the shutdown pin logic
//#define POLOLUSWITCH

static const uint32_t cardCookie = 322417479;


// DFPlayer Mini
SoftwareSerial mySoftwareSerial(3, 2); // RX, TX
uint16_t numTracksInFolder;
uint16_t currentTrack;
uint16_t firstTrack;
uint8_t queue[255];
uint8_t volume;

struct folderSettings {
  uint8_t folder;
  uint8_t mode;
  uint8_t special;
  uint8_t special2;
};

// this object stores nfc tag data
struct nfcTagObject {
  uint32_t cookie;
  uint8_t version;
  folderSettings nfcFolderSettings;
  //  uint8_t folder;
  //  uint8_t mode;
  //  uint8_t special;
  //  uint8_t special2;
};

// admin settings stored in eeprom
struct adminSettings {
  uint32_t cookie;
  byte version;
  uint8_t maxVolume;
  uint8_t minVolume;
  uint8_t initVolume;
  uint8_t eq;
  bool locked;
  long standbyTimer;
  bool invertVolumeButtons;
  folderSettings shortCuts[4];
  uint8_t adminMenuLocked;
  uint8_t adminMenuPin[4];
};

adminSettings mySettings;
nfcTagObject myCard;
folderSettings *myFolder;
unsigned long sleepAtMillis = 0;
static uint16_t _lastTrackFinished;

static void nextTrack(uint16_t track);
uint8_t voiceMenu(int numberOfOptions, int startMessage, int messageOffset,
                  bool preview = false, int previewFromFolder = 0, int defaultValue = 0, bool exitWithLongPress = false);
bool isPlaying();
bool checkTwo ( uint8_t a[], uint8_t b[] );
void writeCard(nfcTagObject nfcTag);
void dump_byte_array(byte * buffer, byte bufferSize);
void adminMenu(bool fromCard = false);
bool knownCard = false;
bool ansage = false;

// implement a notification class,
// its member methods will get called
//
class Mp3Notify {
  public:
    static void OnError(uint16_t returnValue) {
      switch (returnValue) {
        case DfMp3_Error_Busy: {
            Serial.print(F("busy"));
            break;
          }
        case DfMp3_Error_Sleeping: {
            Serial.print(F("sleep"));
            break;
          }
        case DfMp3_Error_SerialWrongStack: {
            Serial.print(F("serial stack"));
            break;
          }
        case DfMp3_Error_CheckSumNotMatch: {
            Serial.print(F("checksum"));
            break;
          }
        case DfMp3_Error_FileIndexOut: {
            Serial.print(F("file index"));
            break;
          }
        case DfMp3_Error_FileMismatch: {
            Serial.print(F("file mismatch"));
            break;
          }
        case DfMp3_Error_Advertise: {
            Serial.print(F("advertise"));
            break;
          }
        case DfMp3_Error_RxTimeout: {
            Serial.print(F("rx timeout"));
            break;
          }
        case DfMp3_Error_PacketSize: {
            Serial.print(F("packet size"));
            break;
          }
        case DfMp3_Error_PacketHeader: {
            Serial.print(F("packet header"));
            break;
          }
        case DfMp3_Error_PacketChecksum: {
            Serial.print(F("packet checksum"));
            break;
          }
        case DfMp3_Error_General: {
            Serial.print(F("general"));
            break;
          }
        default: {
            Serial.print(F("unknown"));
            break;
          }
      }
      Serial.println(F(" error"));
    }
 
    static void PrintlnSourceAction(DfMp3_PlaySources source, const char* action) {
      if (source & DfMp3_PlaySources_Sd) Serial.print("SD Karte ");
      if (source & DfMp3_PlaySources_Usb) Serial.print("USB ");
      if (source & DfMp3_PlaySources_Flash) Serial.print("Flash ");
      Serial.println(action);
    }
    static void OnPlayFinished(DfMp3_PlaySources source, uint16_t track) {
      Serial.print("Track beendet: ");
      delay(500);
      if (!ansage) nextTrack(track); // Spielt den nächsten Track wenn der aktuelle Track kein 000_xxxx Ansagetrack war
     }
    static void OnPlaySourceOnline(DfMp3_PlaySources source) {
      PrintlnSourceAction(source, "online");
    }
    static void OnPlaySourceInserted(DfMp3_PlaySources source) {
      PrintlnSourceAction(source, "bereit");
    }
    static void OnPlaySourceRemoved(DfMp3_PlaySources source) {
      PrintlnSourceAction(source, "entfernt");
    }
};

static DFMiniMp3<SoftwareSerial, Mp3Notify> mp3(mySoftwareSerial);

void shuffleQueue() {
  // Queue für die Zufallswiedergabe erstellen
  for (uint8_t x = 0; x < numTracksInFolder - firstTrack + 1; x++)
    queue[x] = x + firstTrack;
  // Rest mit 0 auffüllen
  for (uint8_t x = numTracksInFolder - firstTrack + 1; x < 255; x++)
    queue[x] = 0;
  // Queue mischen
  for (uint8_t i = 0; i < numTracksInFolder - firstTrack + 1; i++)
  {
    uint8_t j = random (0, numTracksInFolder - firstTrack + 1);
    uint8_t t = queue[i];
    queue[i] = queue[j];
    queue[j] = t;
  }
}

void writeSettingsToFlash() {
  Serial.println(F("=== writeSettingsToFlash()"));
  int address = sizeof(myFolder->folder) * 100;
  EEPROM.put(address, mySettings);
}

void resetSettings() {
  Serial.println(F("=== resetSettings()"));
  mySettings.cookie = cardCookie;
  mySettings.version = 2;
  mySettings.maxVolume = 25;
  mySettings.minVolume = 2;
  mySettings.initVolume = 15;
  mySettings.eq = 1;
  mySettings.locked = false;
  mySettings.standbyTimer = 5;
  mySettings.invertVolumeButtons = true;
mySettings.shortCuts[0].folder = 3; // Ordner bei langem Druck auf mittlerer Taste abspielen
  mySettings.shortCuts[0].mode = 3;   // Party-Modus
  mySettings.shortCuts[1].folder = 4; // Ordner bei langem Druck auf rechter Taste abspielen
  mySettings.shortCuts[1].mode = 3;   // Party-Modus
  mySettings.shortCuts[2].folder = 2; // Ordner bei langem Druck auf linke Taste abspielen
  mySettings.shortCuts[2].mode = 3;   // Party-Modus
  mySettings.shortCuts[3].folder = 1; // Odner beim Start abspielen
  mySettings.shortCuts[3].mode = 3;   // Party-Modus
  mySettings.adminMenuLocked = 0;
  mySettings.adminMenuPin[0] = 1;
  mySettings.adminMenuPin[1] = 1;
  mySettings.adminMenuPin[2] = 1;
  mySettings.adminMenuPin[3] = 1;
  writeSettingsToFlash();
}

void migrateSettings(int oldVersion) {
  if (oldVersion == 1) {
    Serial.println(F("=== resetSettings()"));
    Serial.println(F("1 -> 2"));
    mySettings.version = 2;
    mySettings.adminMenuLocked = 0;
    mySettings.adminMenuPin[0] = 1;
    mySettings.adminMenuPin[1] = 1;
    mySettings.adminMenuPin[2] = 1;
    mySettings.adminMenuPin[3] = 1;
    writeSettingsToFlash();
  }
}

void loadSettingsFromFlash() {
  Serial.println(F("=== loadSettingsFromFlash()"));
  int address = sizeof(myFolder->folder) * 100;
  EEPROM.get(address, mySettings);
  if (mySettings.cookie != cardCookie)
    resetSettings();
  migrateSettings(mySettings.version);

  Serial.print(F("Version: "));
  Serial.println(mySettings.version);

  Serial.print(F("Maximal Volume: "));
  Serial.println(mySettings.maxVolume);

  Serial.print(F("Minimal Volume: "));
  Serial.println(mySettings.minVolume);

  Serial.print(F("Initial Volume: "));
  Serial.println(mySettings.initVolume);

  Serial.print(F("EQ: "));
  Serial.println(mySettings.eq);

  Serial.print(F("Locked: "));
  Serial.println(mySettings.locked);

  Serial.print(F("Sleep Timer: "));
  Serial.println(mySettings.standbyTimer);

  Serial.print(F("Inverted Volume Buttons: "));
  Serial.println(mySettings.invertVolumeButtons);

  Serial.print(F("Admin Menu locked: "));
  Serial.println(mySettings.adminMenuLocked);

  Serial.print(F("Admin Menu Pin: "));
  Serial.print(mySettings.adminMenuPin[0]);
  Serial.print(mySettings.adminMenuPin[1]);
  Serial.print(mySettings.adminMenuPin[2]);
  Serial.println(mySettings.adminMenuPin[3]);
}

class Modifier {
  public:
    virtual void loop() {}
    virtual bool handlePause() {
      return false;
    }
    virtual bool handleNext() {
      return false;
    }
    virtual bool handlePrevious() {
      return false;
    }
    virtual bool handleNextButton() {
      return false;
    }
    virtual bool handlePreviousButton() {
      return false;
    }
    virtual bool handleVolumeUp() {
      return false;
    }
    virtual bool handleVolumeDown() {
      return false;
    }
    virtual bool handleRFID(nfcTagObject *newCard) {
      return false;
    }
    virtual uint8_t getActive() {
      return 0;
    }
    Modifier() {

    }
};

Modifier *activeModifier = NULL;

class SleepTimer: public Modifier {
  private:
    unsigned long sleepAtMillis = 0;

  public:
    void loop() {
      if (this->sleepAtMillis != 0 && millis() > this->sleepAtMillis) {
        Serial.println(F("=== SleepTimer::loop() -> SLEEP!"));
        mp3.pause();
        setstandbyTimer();
        activeModifier = NULL;
        delete this;
      }
    }

    SleepTimer(uint8_t minutes) {
      Serial.println(F("=== SleepTimer()"));
      Serial.println(minutes);
      this->sleepAtMillis = millis() + minutes * 60000;
      //      if (isPlaying())
      //        mp3.playAdvertisement(302);
      //      delay(500);
    }
    uint8_t getActive() {
      Serial.println(F("== SleepTimer::getActive()"));
      return 1;
    }
};

class FreezeDance: public Modifier {
  private:
    unsigned long nextStopAtMillis = 0;
    const uint8_t minSecondsBetweenStops = 5;
    const uint8_t maxSecondsBetweenStops = 30;

    void setNextStopAtMillis() {
      uint16_t seconds = random(this->minSecondsBetweenStops, this->maxSecondsBetweenStops + 1);
      Serial.println(F("=== FreezeDance::setNextStopAtMillis()"));
      Serial.println(seconds);
      this->nextStopAtMillis = millis() + seconds * 1000;
    }

  public:
    void loop() {
      if (this->nextStopAtMillis != 0 && millis() > this->nextStopAtMillis) {
        Serial.println(F("== FreezeDance::loop() -> FREEZE!"));
        if (isPlaying()) {
          mp3.playAdvertisement(301);
          delay(500);
        }
        setNextStopAtMillis();
      }
    }
    FreezeDance(void) {
      Serial.println(F("=== FreezeDance()"));
      if (isPlaying()) {
        delay(1000);
        mp3.playAdvertisement(300);
        delay(500);
      }
      setNextStopAtMillis();
    }
    uint8_t getActive() {
      Serial.println(F("== FreezeDance::getActive()"));
      return 2;
    }
};

class Locked: public Modifier {
  public:
    virtual bool handlePause()     {
      Serial.println(F("== Locked::handlePause() -> LOCKED!"));
      return true;
    }
    virtual bool handleNextButton()       {
      Serial.println(F("== Locked::handleNextButton() -> LOCKED!"));
      return true;
    }
    virtual bool handlePreviousButton() {
      Serial.println(F("== Locked::handlePreviousButton() -> LOCKED!"));
      return true;
    }
    virtual bool handleVolumeUp()   {
      Serial.println(F("== Locked::handleVolumeUp() -> LOCKED!"));
      return true;
    }
    virtual bool handleVolumeDown() {
      Serial.println(F("== Locked::handleVolumeDown() -> LOCKED!"));
      return true;
    }
    virtual bool handleRFID(nfcTagObject *newCard) {
      Serial.println(F("== Locked::handleRFID() -> LOCKED!"));
      return true;
    }
    Locked(void) {
      Serial.println(F("=== Locked()"));
      //      if (isPlaying())
      //        mp3.playAdvertisement(303);
    }
    uint8_t getActive() {
      return 3;
    }
};

class ToddlerMode: public Modifier {
  public:
    virtual bool handlePause()     {
      Serial.println(F("== ToddlerMode::handlePause() -> LOCKED!"));
      return true;
    }
    virtual bool handleNextButton()       {
      Serial.println(F("== ToddlerMode::handleNextButton() -> LOCKED!"));
      return true;
    }
    virtual bool handlePreviousButton() {
      Serial.println(F("== ToddlerMode::handlePreviousButton() -> LOCKED!"));
      return true;
    }
    virtual bool handleVolumeUp()   {
      Serial.println(F("== ToddlerMode::handleVolumeUp() -> LOCKED!"));
      return true;
    }
    virtual bool handleVolumeDown() {
      Serial.println(F("== ToddlerMode::handleVolumeDown() -> LOCKED!"));
      return true;
    }
    ToddlerMode(void) {
      Serial.println(F("=== ToddlerMode()"));
      //      if (isPlaying())
      //        mp3.playAdvertisement(304);
    }
    uint8_t getActive() {
      Serial.println(F("== ToddlerMode::getActive()"));
      return 4;
    }
};
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
void loop() {
  do {
    checkStandbyAtMillis();
    mp3.loop();

    // Modifier : WIP!
    if (activeModifier != NULL) {
      activeModifier->loop();
    }

    // Buttons werden nun über JS_Button gehandelt, dadurch kann jede Taste doppelt belegt werden
    readButtons();
    // admin menu
    if ((pauseButton.pressedFor(LONG_PRESS) || upButton.pressedFor(LONG_PRESS) || downButton.pressedFor(LONG_PRESS)) && pauseButton.isPressed() && upButton.isPressed() && downButton.isPressed()) {
      mp3.pause();
      do {
        readButtons();
      } while (pauseButton.isPressed() || upButton.isPressed() || downButton.isPressed());
      readButtons();
      adminMenu();
      break;
    }
    if (pauseButton.wasReleased()) {
      if (activeModifier != NULL)
        if (activeModifier->handlePause() == true)
          return;
      if (ignorePauseButton == false)
        if (isPlaying()) {
          mp3.pause();
          setstandbyTimer();
        }
        else if (knownCard) {
          mp3.start();
          disablestandbyTimer();
        }
      ignorePauseButton = false;
    } else if (pauseButton.pressedFor(LONG_PRESS) &&
               ignorePauseButton == false) {
      if (activeModifier != NULL)
        if (activeModifier->handlePause() == true)
          return;
      if (isPlaying()) {
        uint8_t advertTrack;
        if (myFolder->mode == 3 || myFolder->mode == 9) {
          advertTrack = (queue[currentTrack - 1]);
        }
        else {
          advertTrack = currentTrack;
        }
        // Spezialmodus Von-Bis für Album und Party gibt die Dateinummer relativ zur Startposition wieder
        if (myFolder->mode == 8 || myFolder->mode == 9) {
          advertTrack = advertTrack - myFolder->special + 1;
        }
        mp3.playAdvertisement(advertTrack);
      }
      else {
        playShortCut(0);
      }
      ignorePauseButton = true;
    }

    if (upButton.pressedFor(LONG_PRESS)) {
#ifndef FIVEBUTTONS
      if (isPlaying()) {
        if (!mySettings.invertVolumeButtons) {
          volumeUpButton();
        }
        else {
          nextButton();
        }
      }
      else {
        playShortCut(1);
      }
      ignoreUpButton = true;
#endif
    } else if (upButton.wasReleased()) {
      if (!ignoreUpButton)
        if (!mySettings.invertVolumeButtons) {
          nextButton();
        }
        else {
          volumeUpButton();
        }
      ignoreUpButton = false;
    }
    if (downButton.pressedFor(LONG_PRESS)) {
#ifndef FIVEBUTTONS
      if (isPlaying()) {
        if (!mySettings.invertVolumeButtons) {
          volumeDownButton();
        }
        else {
          previousButton();
        }
      }
      else {
        playShortCut(2);
      }
      ignoreDownButton = true;
#endif
    } else if (downButton.wasReleased()) {
      if (!ignoreDownButton) {
        if (!mySettings.invertVolumeButtons) {
          previousButton();
        }
        else {
          volumeDownButton();
        }
      }
      ignoreDownButton = false;
    }
#ifdef FIVEBUTTONS
    if (buttonFour.wasReleased()) {
      if (isPlaying()) {
        if (!mySettings.invertVolumeButtons) {
          volumeUpButton();
        }
        else {
          nextButton();
        }
      }
      else {
        playShortCut(1);
      }
    }
    if (buttonFive.wasReleased()) {
      if (isPlaying()) {
        if (!mySettings.invertVolumeButtons) {
          volumeDownButton();
        }
        else {
          previousButton();
        }
      }
      else {
        playShortCut(2);
      }
    }
#endif
    // Ende der Buttons
  } while (!mfrc522.PICC_IsNewCardPresent());

  // RFID Karte wurde aufgelegt
  if (!mfrc522.PICC_ReadCardSerial())
    return;
  // Bekannte Karte - Spielt Album ab
  if (readCard(&myCard) == true) {
    if (myCard.cookie == cardCookie && myCard.nfcFolderSettings.folder != 0 && myCard.nfcFolderSettings.mode != 0) {
      playFolder();
    }
     // Neue Karte konfigurieren - Programmierung wird aufgerufen
    else if (myCard.cookie != cardCookie) {
      knownCard = false;
      mp3.playMp3FolderTrack(300);
      waitForTrackToFinish();
      setupCard();
    }
  }
  mfrc522.PICC_HaltA();
  mfrc522.PCD_StopCrypto1();
} // ##################### Ende von loop() ################################
void adminMenu(bool fromCard = false) {
  disablestandbyTimer();
  mp3.pause();
  Serial.println(F("=== adminMenu()"));
  knownCard = false;
  if (fromCard == false) {
    // Admin menu has been locked - it still can be trigged via admin card
    if (mySettings.adminMenuLocked == 1) {
      return;
    }
    // Pin check
    else if (mySettings.adminMenuLocked == 2) {
      uint8_t pin[4];
      mp3.playMp3FolderTrack(991);
      if (askCode(pin) == true) {
        if (checkTwo(pin, mySettings.adminMenuPin) == false) {
          return;
        }
      } else {
        return;
      }
    }
    // Match check
    else if (mySettings.adminMenuLocked == 3) {
      uint8_t a = random(10, 20);
      uint8_t b = random(1, 10);
      uint8_t c;
      mp3.playMp3FolderTrack(992);
      waitForTrackToFinish();
      mp3.playMp3FolderTrack(a);

      if (random(1, 3) == 2) {
        // a + b
        c = a + b;
        waitForTrackToFinish();
        mp3.playMp3FolderTrack(993);
      } else {
        // a - b
        b = random(1, a);
        c = a - b;
        waitForTrackToFinish();
        mp3.playMp3FolderTrack(994);
      }
      waitForTrackToFinish();
      mp3.playMp3FolderTrack(b);
      Serial.println(c);
      uint8_t temp = voiceMenu(255, 0, 0, false);
      if (temp != c) {
        return;
      }
    }
  }
  int subMenu = voiceMenu(12, 900, 900, false, false, 0, true);
  if (subMenu == 0)
    return;
  if (subMenu == 1) {
    resetCard();
    mfrc522.PICC_HaltA();
    mfrc522.PCD_StopCrypto1();
  }
  else if (subMenu == 2) {
    // Maximum Volume
    mySettings.maxVolume = voiceMenu(30 - mySettings.minVolume, 930, mySettings.minVolume, false, false, mySettings.maxVolume - mySettings.minVolume) + mySettings.minVolume;
  }
  else if (subMenu == 3) {
    // Minimum Volume
    mySettings.minVolume = voiceMenu(mySettings.maxVolume - 1, 931, 0, false, false, mySettings.minVolume);
  }
  else if (subMenu == 4) {
    // Initial Volume
    mySettings.initVolume = voiceMenu(mySettings.maxVolume - mySettings.minVolume + 1, 932, mySettings.minVolume - 1, false, false, mySettings.initVolume - mySettings.minVolume + 1) + mySettings.minVolume - 1;
  }
  else if (subMenu == 5) {
    // EQ
    mySettings.eq = voiceMenu(6, 920, 920, false, false, mySettings.eq);
    mp3.setEq(mySettings.eq - 1);
  }
  else if (subMenu == 6) {
    // create modifier card
    nfcTagObject tempCard;
    tempCard.cookie = cardCookie;
    tempCard.version = 1;
    tempCard.nfcFolderSettings.folder = 0;
    tempCard.nfcFolderSettings.special = 0;
    tempCard.nfcFolderSettings.special2 = 0;
    tempCard.nfcFolderSettings.mode = voiceMenu(6, 970, 970, false, false, 0, true);

    if (tempCard.nfcFolderSettings.mode != 0) {
      if (tempCard.nfcFolderSettings.mode == 1) {
        switch (voiceMenu(4, 960, 960)) {
          case 1: tempCard.nfcFolderSettings.special = 5; break;
          case 2: tempCard.nfcFolderSettings.special = 15; break;
          case 3: tempCard.nfcFolderSettings.special = 30; break;
          case 4: tempCard.nfcFolderSettings.special = 60; break;
        }
      }
      mp3.playMp3FolderTrack(800);
      do {
        readButtons();
        if (upButton.wasReleased() || downButton.wasReleased()) {
          Serial.println(F("Abgebrochen!"));
          mp3.playMp3FolderTrack(802);
          return;
        }
      } while (!mfrc522.PICC_IsNewCardPresent());
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

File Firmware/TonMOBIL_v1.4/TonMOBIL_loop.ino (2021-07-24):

// ########################################### loop() #######################################################
void loop() {
  do {
    checkStandbyAtMillis();
    mp3.loop();

    // Modifier : WIP!
    if (activeModifier != NULL) {
      activeModifier->loop();
    }

#ifdef LED_SR
    // LED Strip
    //Prüfung der einmaligen Animationen 
    // Liedänderung erkennen und Animation aktivieren
    currentDetectedTrack = currentTrack;
    if (currentDetectedTrack != lastDetectedTrack){
      strip.clear();
      if (currentTrack > lastDetectedTrack) { //nächstes Lied
        lsrAnimationTrackMode = 1;
        lsrColors = lsrColorUp;
      }
      if (currentTrack < lastDetectedTrack) { // Lied zurück
        lsrAnimationTrackMode = 2;
        lsrColors = lsrColorDown;
      }
      lsrAnimationMode = 1;
      animationCountdown = strip.numPixels();
      lsrLoopCountWait = 5; // Geschwindigkeit der Animation, desto größer desto langsamer
      y = 0;
    }

    // Lautstärkenanpassung erkennen und Animation aktivieren
    currentDetectedVolume = volume;
    if (currentDetectedVolume != lastDetectedVolume) {
      lsrAnimationMode = 2;
      animationCountdown = strip.numPixels();
      lsrLoopCountWait = 6;
      y = 0;
    }

    // Dauerhafte Loop Animationen
    // Loop Animation: Default Mode
    if (lsrAnimationMode == 0 && loopCountdown == 0 && isPlaying() == false && knownCard == false) {
      lsrLoopCountWait = 1; // Geschwindigkeit der Animation, desto größer desto langsamer

      // Farbe & Animation definieren: Alle LEDs leuchten alle abwechselnd  im hue Spektrum
      y++;
      if (y >= (strip.numPixels() * 8) ) {
        y = 0;
      }
      strip.fill(strip.ColorHSV((y * 65536 / strip.numPixels() / 8) , 255, 30), 0, 0);
      strip.show();
      loopCountdown = lsrLoopCountWait;
    }

    // Loop Animation: Musik spielt
    if (lsrAnimationMode == 0 && loopCountdown == 0 && isPlaying() == true && knownCard == true) {
      lsrLoopCountWait = 5; // Geschwindigkeit der Animation, desto größer desto langsamer
      // Fabre definieren: hue Spektrum (Rainbow)
      do {
        for (i = 0; i < strip.numPixels(); i++) {
          lsrColors = strip.ColorHSV(i * 65536 / strip.numPixels(), 255, 30);
          strip.setPixelColor(i, lsrColors);
          lsrColorR[i] = (lsrColors >> 16 & 0xFF);
          lsrColorG[i] = (lsrColors >> 8 & 0xFF);
          lsrColorB[i] = (lsrColors & 0xFF);
        }
        x++;
      } while (x < strip.numPixels());
      // Animation definieren: Rotation im Uhrzeigersinn
      y++;
      x = 0;
      if (y >= strip.numPixels())
      {
        y = 0;
      }
      do
      {
        for (i = 0; i < strip.numPixels(); i++)
        {
          strip.setPixelColor((i + y) % strip.numPixels(), lsrColorR[i], lsrColorG[i], lsrColorB[i]);
        }
        x++;
      } while (x < strip.numPixels());

      strip.show();
      loopCountdown = lsrLoopCountWait;
    }

    // Loop Animation: Musik pausiert
    if (lsrAnimationMode == 0 && loopCountdown == 0 && isPlaying() == false && knownCard == true) {
      lsrLoopCountWait = 7; // Geschwindigkeit der Animation, desto größer desto langsamer
      // Fabre definieren: hue Spektrum (Rainbow)
      strip.clear();   // Danach nur ein Punkt
      x = 0;
      do {
        for (i = 0; i < strip.numPixels(); i++) {
          lsrColors = strip.ColorHSV(i * 65536 / strip.numPixels(), 255, 30);
          lsrColorR[i] = (lsrColors >> 16 & 0xFF);
          lsrColorG[i] = (lsrColors >> 8 & 0xFF);
          lsrColorB[i] = (lsrColors & 0xFF);
        }
        x++;
      } while (x < strip.numPixels());
      // Farbe definieren: Füllend ansteigend
      y++;
      if (y >= strip.numPixels()) {
        y = 0;
        z++;
        strip.clear();
      }
      if (z >= strip.numPixels()) {
        z = 0;
      }
      x = 0;
      do {
        for (i = 0; i < y + 1 ; i++) {
          strip.setPixelColor( y , lsrColorR[y], lsrColorG[y], lsrColorB[y]);
        }
        x++;
      } while (x < y + 1);
      strip.show();
      loopCountdown = lsrLoopCountWait;
    }
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

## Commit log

2021-07-26 Neuordnung der Gehäusebauteile
    [5V.stl, Bügel.stl, Bügelbuchse.stl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]
2021-07-26 Neue NFC-Tiere
    [Bär-Boden.stl, Bär.stl, Eichhörnchen-Boden.stl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]
2021-07-26 Bilder der NFC-Tiere
2021-07-26 Create NFC-Tiere
    [Die_Maus-Boden.stl]
2021-07-27 Neue Figuren
    [Die_Maus-Boden.stl, Elefant-Boden.stl, Elefant-Bodendeckel.stl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]
2021-07-31 Update Maus
    [Die Maus-Boden.stl, Die_Maus-Boden.stl]
2023-12-25 Einstellung für Arduino-IDE
